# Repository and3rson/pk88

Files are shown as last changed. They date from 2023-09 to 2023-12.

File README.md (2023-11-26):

# PK88

Single-board computer based on KM1810VM88 CPU (Ukrainian clone of Intel 8088) that can run ELKS!

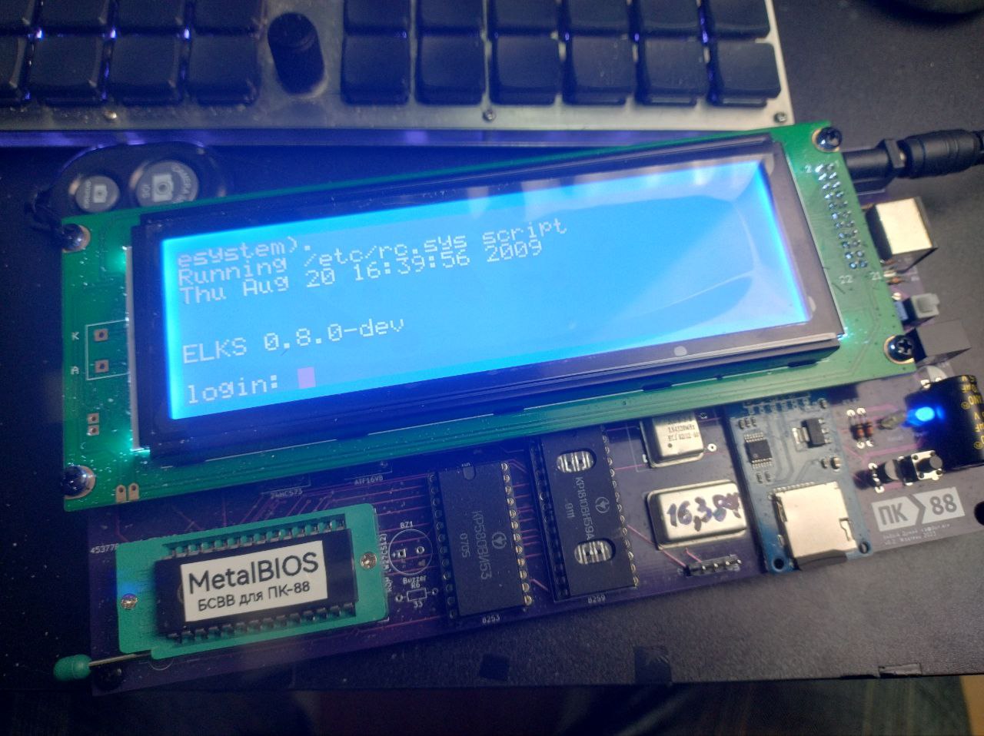
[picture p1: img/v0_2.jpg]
ELKS


PK stands for Персональний Комп'ютер ("Personalnii Kompyuter", i.e. "Personal Computer") in Ukrainian.

This board runs @ 8 MHz (24 MHz oscillator) in minimum mode.

- [KiCad schematics](./kicad)
- [GAL sources](./gal) - Address & I/O port decoders using 2x ATF16V8
- [Various circuit simulations](./circuits) - made with [Digital](https://github.com/hneemann/Digital)
- [MetalBIOS](./metalbios) - IBM PC XT compatible-ish BIOS that I made specifically for PK-88

## Resources

- 8088/x86 instruction set: <https://zsmith.co/intel.php>
- Zen of Assembly language (including 8088 instruction set): <http://www.jagregory.com/abrash-zen-of-asm/>
- Soviet IC series differences: <http://vozom.ho.ua/R4/page21.html>
- IBM PC technical reference: <http://bitsavers.informatik.uni-stuttgart.de/pdf/ibm/pc/at/6183355_PC_AT_Technical_Reference_Mar86.pdf>

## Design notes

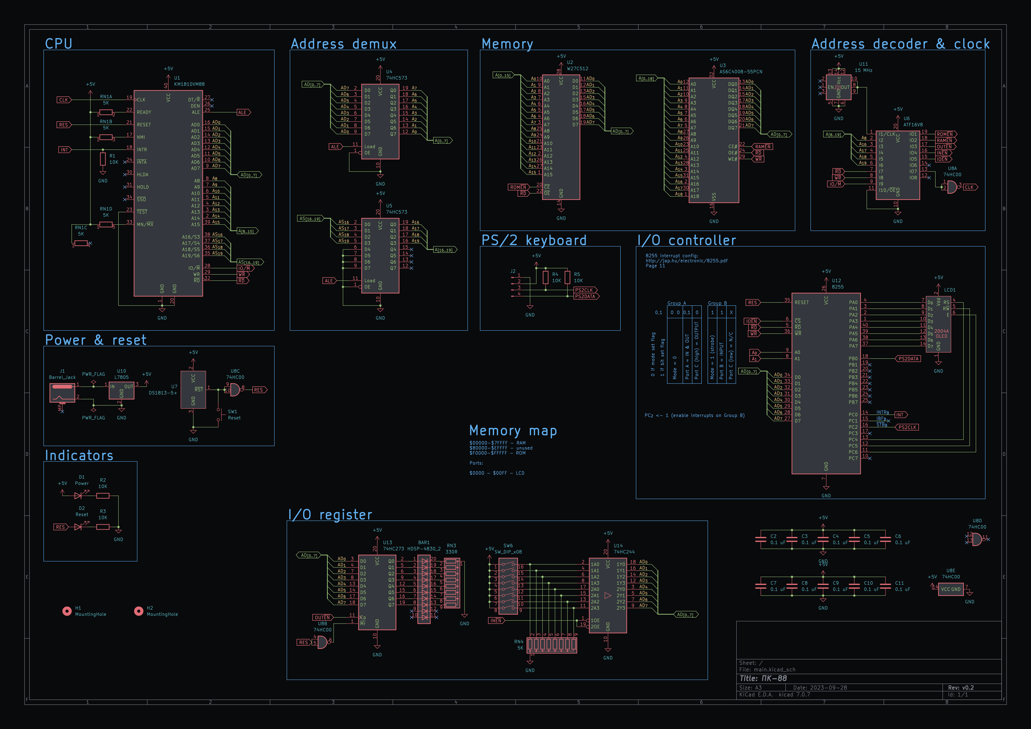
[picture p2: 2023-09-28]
img/v02_schematic.png

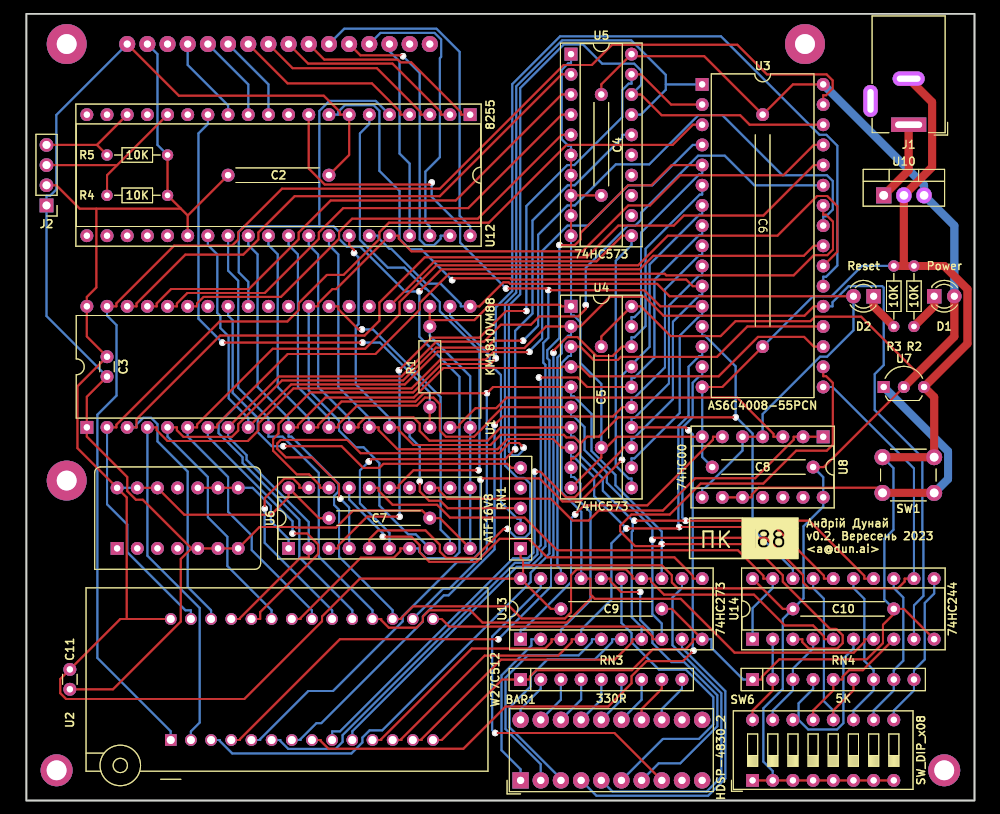
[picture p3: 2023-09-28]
img/v02_pcb_1.png

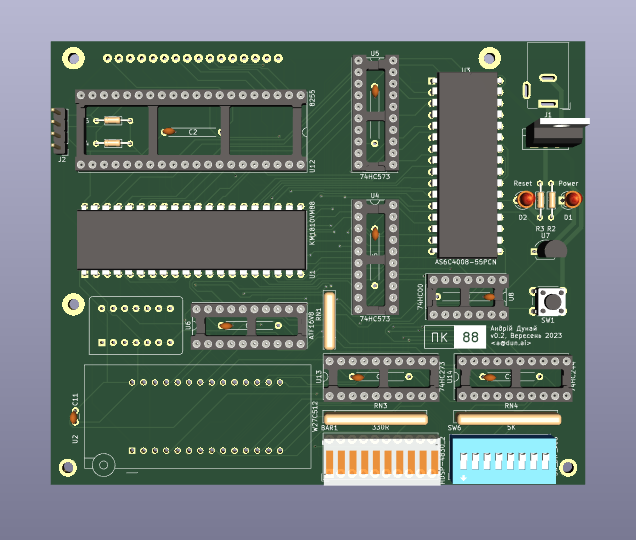
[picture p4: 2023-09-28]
img/v02_3d.png

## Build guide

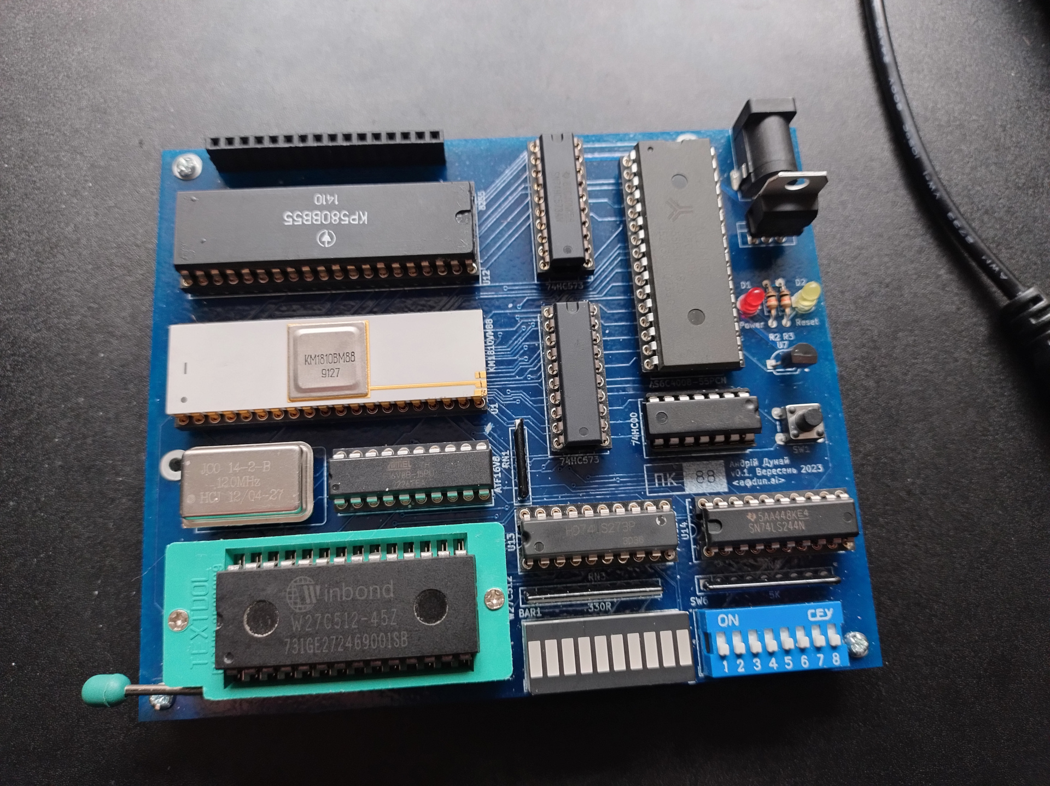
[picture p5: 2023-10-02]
img/v0_1_assembled1.jpg

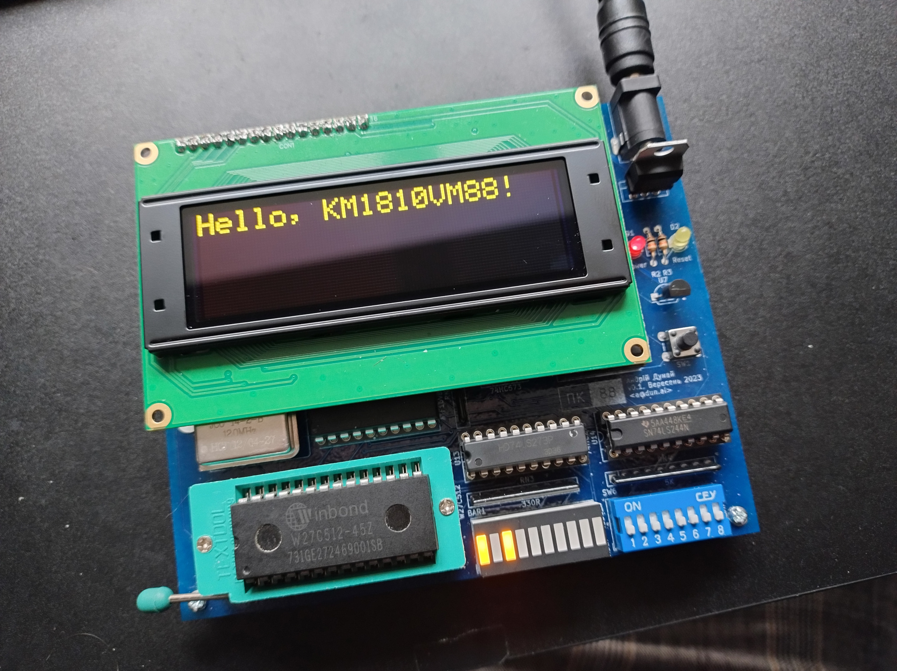
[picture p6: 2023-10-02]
img/v0_1_assembled2.jpg

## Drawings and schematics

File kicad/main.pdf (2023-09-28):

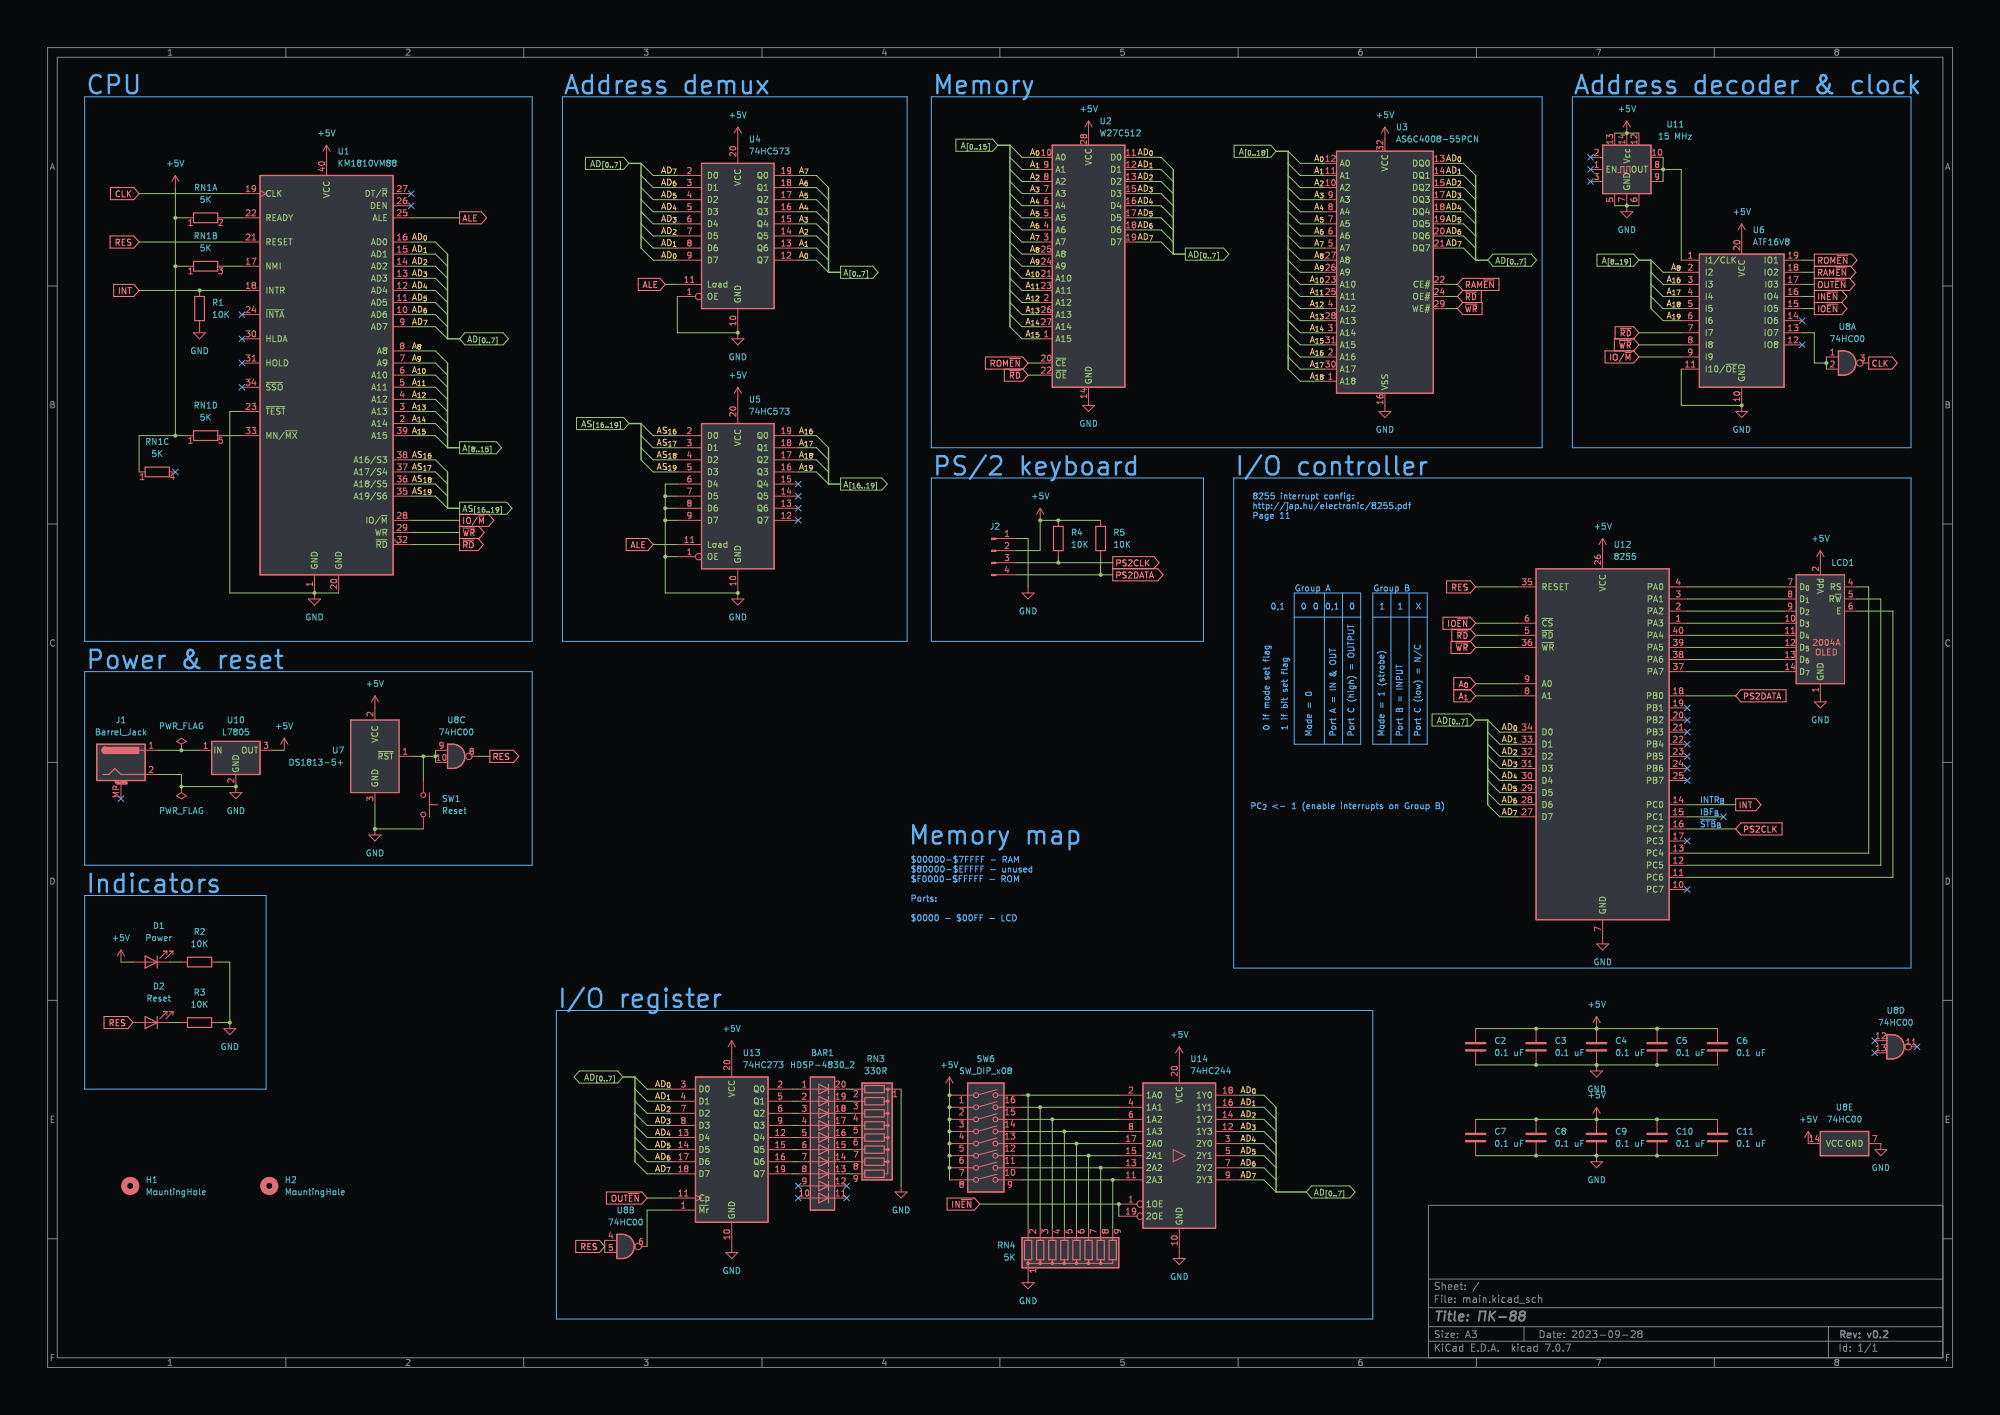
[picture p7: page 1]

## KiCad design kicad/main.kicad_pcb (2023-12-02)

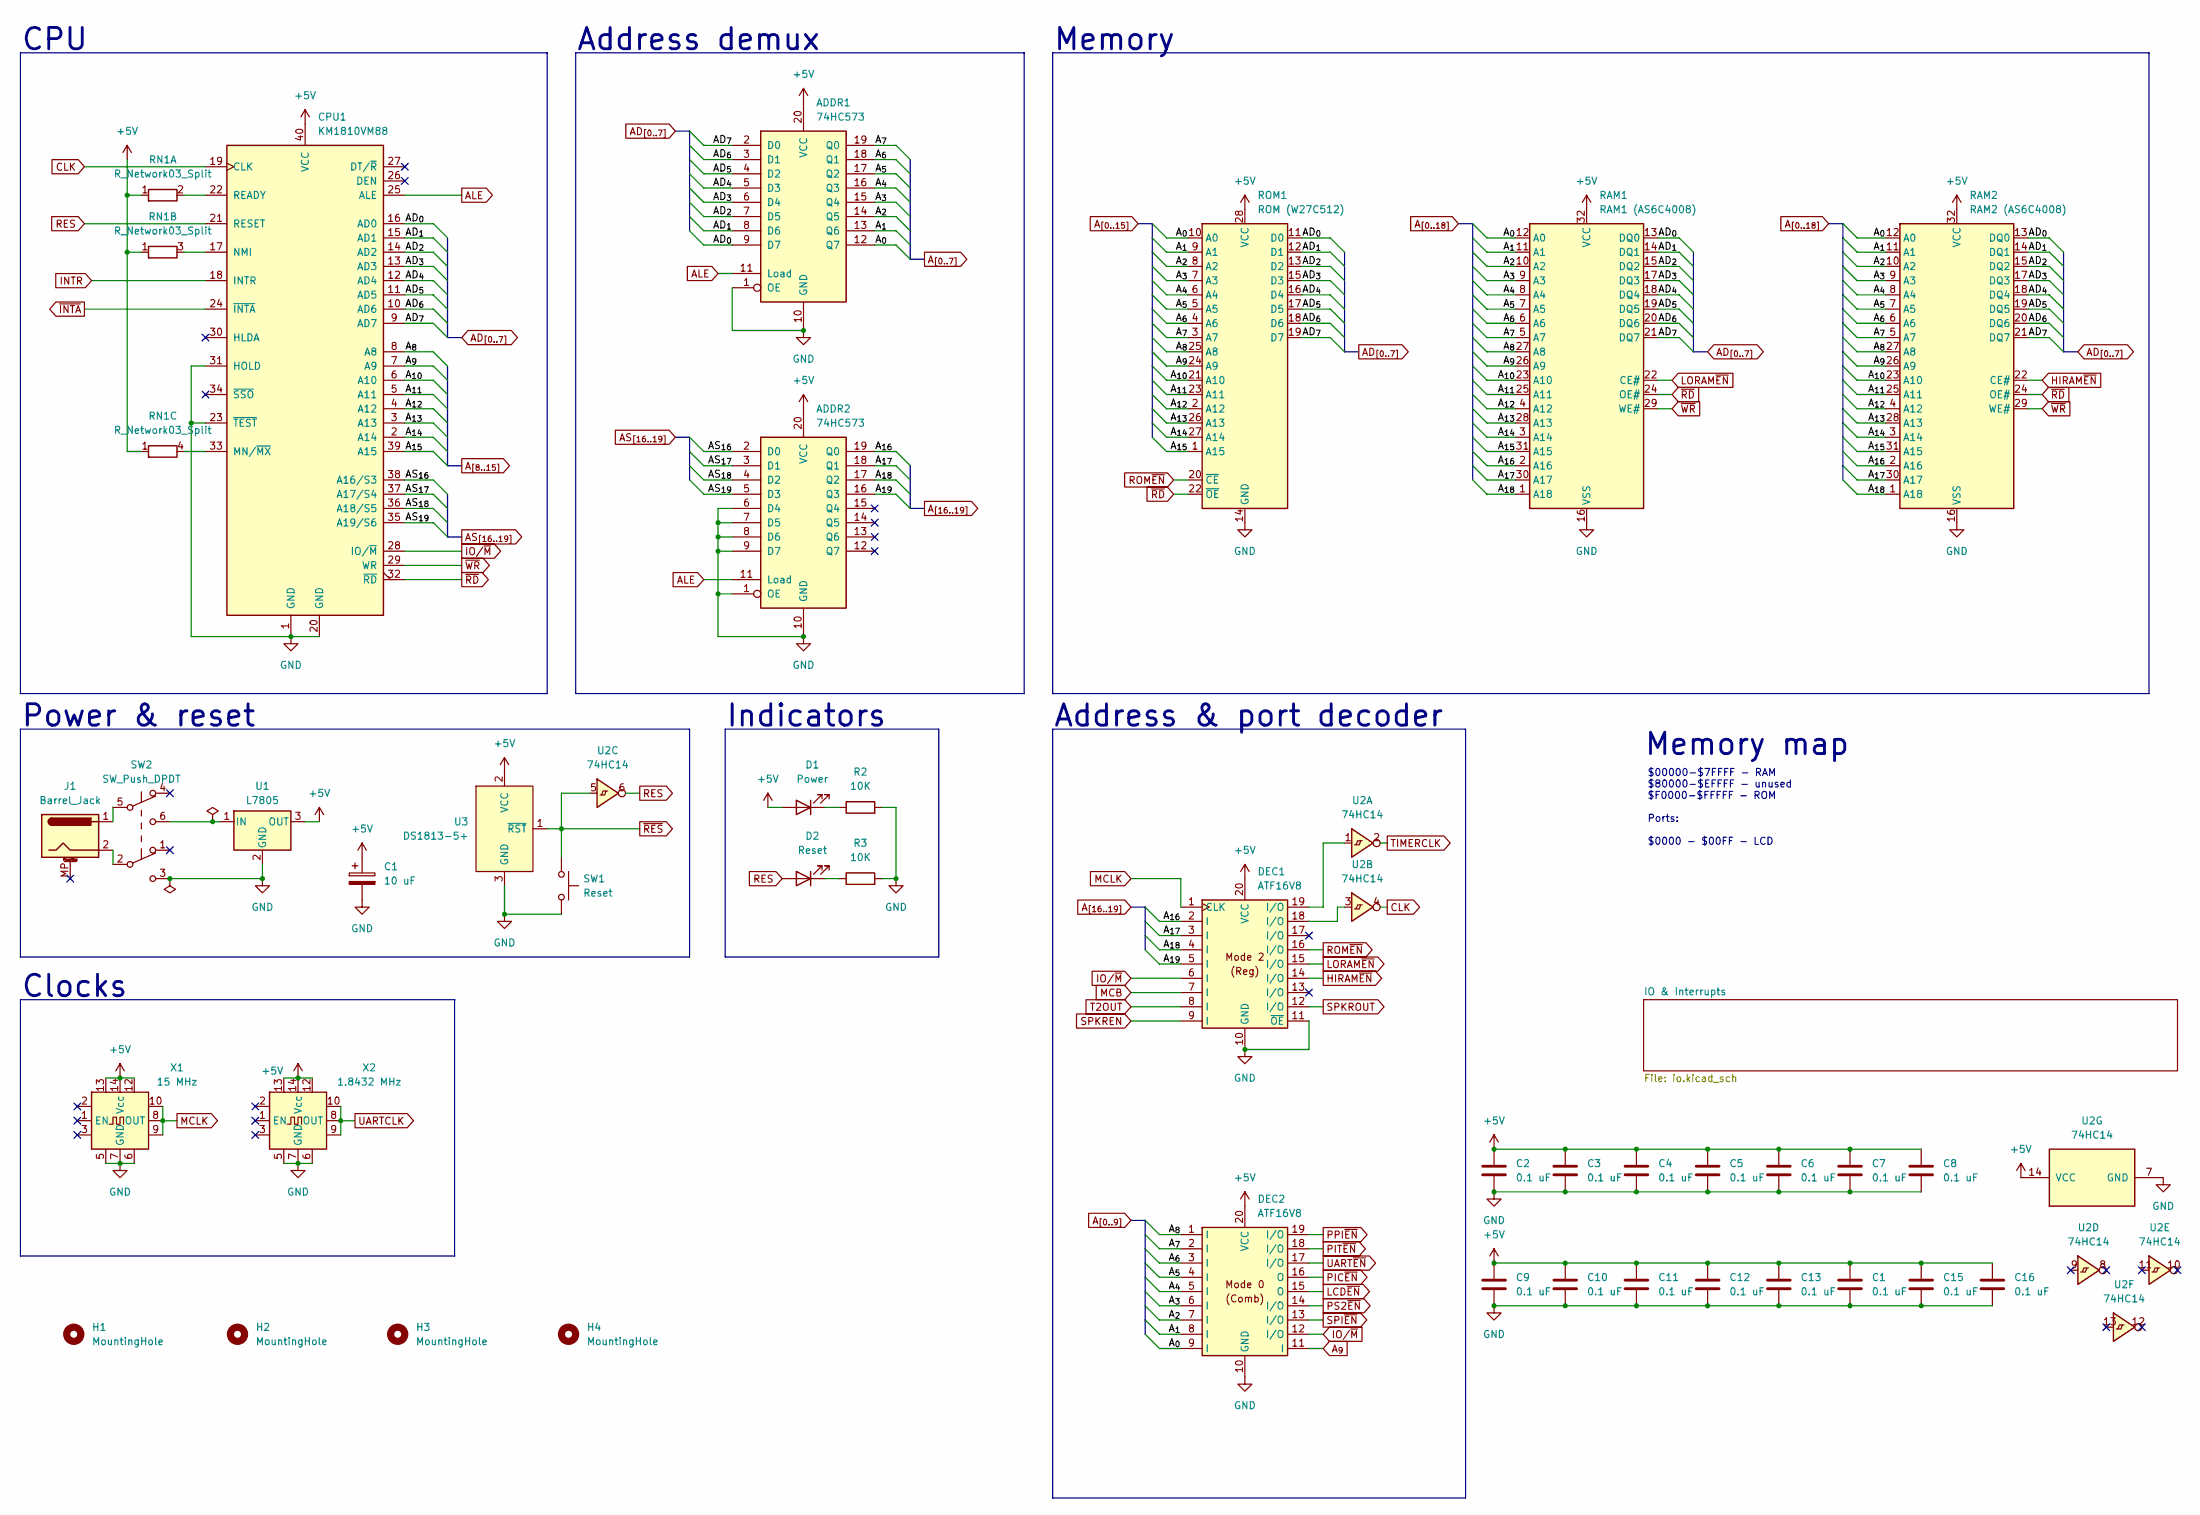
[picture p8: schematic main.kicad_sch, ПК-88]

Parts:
ADDR1, ADDR2: 74HC573; DIP-20_W7.62mm_Socket
C1: 10 uF; CP_Radial_D8.0mm_P3.50mm
C2, C4, C5, C7, C8, C10, C15, C16: 0.1 uF; C_Disc_Long
C3, C11: 0.1 uF; C_Disc_D3.0mm_W1.6mm_P2.50mm
C6, C9, C12, C13: 0.1 uF; C_Disc_VeryLong
CPU1: KM1810VM88; DIP-40_W15.24mm
D1: Power; LED_D3.0mm
D2: Reset; LED_D3.0mm
DEC1, DEC2: ATF16V8; DIP-20_W7.62mm_Socket
H1, H2, H3, H4: MountingHole; Hole_3.5x5
J1: Barrel_Jack; BarrelJack_Wuerth_6941xx301002
R2, R3: 10K; R_Axial_DIN0204_L3.6mm_D1.6mm_P7.62mm_Horizontal
RAM1: RAM1 (AS6C4008); DIP-32_W15.24mm
RAM2: RAM2 (AS6C4008); DIP-32_W15.24mm
RN1: R_Network03_Split; R_Array_SIP4
ROM1: ROM (W27C512); ZIF28
SW1: Reset; SW_PUSH_6mm_H5mm
SW2: SW_Push_DPDT; PB22E06
U1: L7805; TO-220-3_Vertical
U2: 74HC14; DIP-14_W7.62mm_Socket
U3: DS1813-5+; TO-92L_Inline_Wide
X1: 15 MHz; Oscillator_DIP-8-14
X2: 1.8432 MHz; Oscillator_DIP-8-14

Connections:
+5V: ADDR1.20 (VCC), ADDR2.20 (VCC), C1.1, C2.1, C3.1, C4.1, C5.1, C6.1, C7.1, C8.1, C9.1, C10.1, C11.1, C12.1, C13.1, C15.1, C16.1, CPU1.40 (VCC), D1.2 (A), DEC1.20 (VCC), DEC2.20 (VCC), RAM1.32 (VCC), RAM2.32 (VCC), RN1.1 (R1), ROM1.28 (VCC), U1.3 (OUT), U2.14 (VCC), U3.2 (VCC), X1.12, X1.13, X1.14 (Vcc), X2.12, X2.13, X2.14 (Vcc); also elsewhere on the board
AD_{0}: ADDR1.9 (D7), CPU1.16 (AD0), RAM1.13 (DQ0), RAM2.13 (DQ0), ROM1.11 (D0); also elsewhere on the board
AD_{1}: ADDR1.8 (D6), CPU1.15 (AD1), RAM1.14 (DQ1), RAM2.14 (DQ1), ROM1.12 (D1); also elsewhere on the board
AD_{2}: ADDR1.7 (D5), CPU1.14 (AD2), RAM1.15 (DQ2), RAM2.15 (DQ2), ROM1.13 (D2); also elsewhere on the board
AD_{3}: ADDR1.6 (D4), CPU1.13 (AD3), RAM1.17 (DQ3), RAM2.17 (DQ3), ROM1.15 (D3); also elsewhere on the board
AD_{4}: ADDR1.5 (D3), CPU1.12 (AD4), RAM1.18 (DQ4), RAM2.18 (DQ4), ROM1.16 (D4); also elsewhere on the board
AD_{5}: ADDR1.4 (D2), CPU1.11 (AD5), RAM1.19 (DQ5), RAM2.19 (DQ5), ROM1.17 (D5); also elsewhere on the board
AD_{6}: ADDR1.3 (D1), CPU1.10 (AD6), RAM1.20 (DQ6), RAM2.20 (DQ6), ROM1.18 (D6); also elsewhere on the board
AD_{7}: ADDR1.2 (D0), CPU1.9 (AD7), RAM1.21 (DQ7), RAM2.21 (DQ7), ROM1.19 (D7); also elsewhere on the board
ALE: ADDR1.11 (Load), ADDR2.11 (Load), CPU1.25 (ALE)
AS_{16}: ADDR2.2 (D0), CPU1.38 (A16/S3)
AS_{17}: ADDR2.3 (D1), CPU1.37 (A17/S4)
AS_{18}: ADDR2.4 (D2), CPU1.36 (A18/S5)
AS_{19}: ADDR2.5 (D3), CPU1.35 (A19/S6)
A_{0}: ADDR1.12 (Q7), DEC2.9 (I), RAM1.12 (A0), RAM2.12 (A0), ROM1.10 (A0); also elsewhere on the board
A_{1}: ADDR1.13 (Q6), DEC2.8 (I), RAM1.11 (A1), RAM2.11 (A1), ROM1.9 (A1); also elsewhere on the board
A_{2}: ADDR1.14 (Q5), DEC2.7 (I), RAM1.10 (A2), RAM2.10 (A2), ROM1.8 (A2); also elsewhere on the board
A_{3}: ADDR1.15 (Q4), DEC2.6 (I), RAM1.9 (A3), RAM2.9 (A3), ROM1.7 (A3)
A_{4}: ADDR1.16 (Q3), DEC2.5 (I), RAM1.8 (A4), RAM2.8 (A4), ROM1.6 (A4)
A_{5}: ADDR1.17 (Q2), DEC2.4 (I), RAM1.7 (A5), RAM2.7 (A5), ROM1.5 (A5)
A_{6}: ADDR1.18 (Q1), DEC2.3 (I), RAM1.6 (A6), RAM2.6 (A6), ROM1.4 (A6)
A_{7}: ADDR1.19 (Q0), DEC2.2 (I), RAM1.5 (A7), RAM2.5 (A7), ROM1.3 (A7)
A_{8}: CPU1.8 (A8), DEC2.1 (I), RAM1.27 (A8), RAM2.27 (A8), ROM1.25 (A8)
A_{9}: CPU1.7 (A9), DEC2.11 (I), RAM1.26 (A9), RAM2.26 (A9), ROM1.24 (A9)
A_{10}: CPU1.6 (A10), RAM1.23 (A10), RAM2.23 (A10), ROM1.21 (A10)
A_{11}: CPU1.5 (A11), RAM1.25 (A11), RAM2.25 (A11), ROM1.23 (A11)
A_{12}: CPU1.4 (A12), RAM1.4 (A12), RAM2.4 (A12), ROM1.2 (A12)
A_{13}: CPU1.3 (A13), RAM1.28 (A13), RAM2.28 (A13), ROM1.26 (A13)
A_{14}: CPU1.2 (A14), RAM1.3 (A14), RAM2.3 (A14), ROM1.27 (A14)
A_{15}: CPU1.39 (A15), RAM1.31 (A15), RAM2.31 (A15), ROM1.1 (A15)
A_{16}: ADDR2.19 (Q0), DEC1.2 (I), RAM1.2 (A16), RAM2.2 (A16)
A_{17}: ADDR2.18 (Q1), DEC1.3 (I), RAM1.30 (A17), RAM2.30 (A17)
A_{18}: ADDR2.17 (Q2), DEC1.4 (I), RAM1.1 (A18), RAM2.1 (A18)
A_{19}: ADDR2.16 (Q3), DEC1.5 (I)
CLK: CPU1.19 (CLK), U2.4; also elsewhere on the board
HIRAM~EN: DEC1.14 (I/O), RAM2.22 (CE#)
INTR: CPU1.18 (INTR); also elsewhere on the board
IO/~M: CPU1.28 (IO/~M), DEC1.6 (I), DEC2.12 (I/O)
LCD~EN: DEC2.15 (O); also elsewhere on the board
LORAM~EN: DEC1.15 (I/O), RAM1.22 (CE#)
MCLK: DEC1.1 (CLK), X1.8 (OUT), X1.9, X1.10
unnamed: CPU1.33 (MN/~MX), RN1.4 (R3.2)
unnamed: CPU1.17 (NMI), RN1.3 (R2.2)
unnamed: CPU1.22 (READY), RN1.2 (R1.2)
unnamed: D2.1 (K), R3.1
unnamed: DEC1.18 (I/O), U2.3
unnamed: DEC1.19 (I/O), U2.1
unnamed: J1.1, SW2.5 (B)
unnamed: J1.2, SW2.2 (B)
unnamed: SW2.6 (C), U1.1 (IN)
PIC~EN: DEC2.16 (O); also elsewhere on the board
PIT~EN: DEC2.18 (I/O); also elsewhere on the board
PPI~EN: DEC2.19 (I/O); also elsewhere on the board
PS2~EN: DEC2.14 (I/O); also elsewhere on the board
RES: CPU1.21 (RESET), D2.2 (A), U2.6; also elsewhere on the board
ROM~EN: DEC1.16 (I/O), ROM1.20 (~CE)
SPI~EN: DEC2.13 (I/O); also elsewhere on the board
SPKREN: DEC1.9 (I); also elsewhere on the board
SPKROUT: DEC1.12 (I/O); also elsewhere on the board
T2OUT: DEC1.8 (I); also elsewhere on the board
TIMERCLK: U2.2; also elsewhere on the board
UARTCLK: X2.8 (OUT), X2.9, X2.10; also elsewhere on the board
UART~EN: DEC2.17 (I/O); also elsewhere on the board
~INTA: CPU1.24 (~INTA); also elsewhere on the board
~RD: CPU1.32 (~RD), RAM1.24 (OE#), RAM2.24 (OE#), ROM1.22 (~OE); also elsewhere on the board
~RES: SW1.1, U2.5, U3.1 (~RST); also elsewhere on the board
~WR: CPU1.29 (WR), RAM1.29 (WE#), RAM2.29 (WE#); also elsewhere on the board

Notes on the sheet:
Address & port decoder
Clocks
Power & reset
Address demux
Indicators
Memory
$00000-$7FFFF - RAM $80000-$EFFFF - unused $F0000-$FFFFF - ROM Ports: $0000 - $00FF - LCD
Memory map
CPU

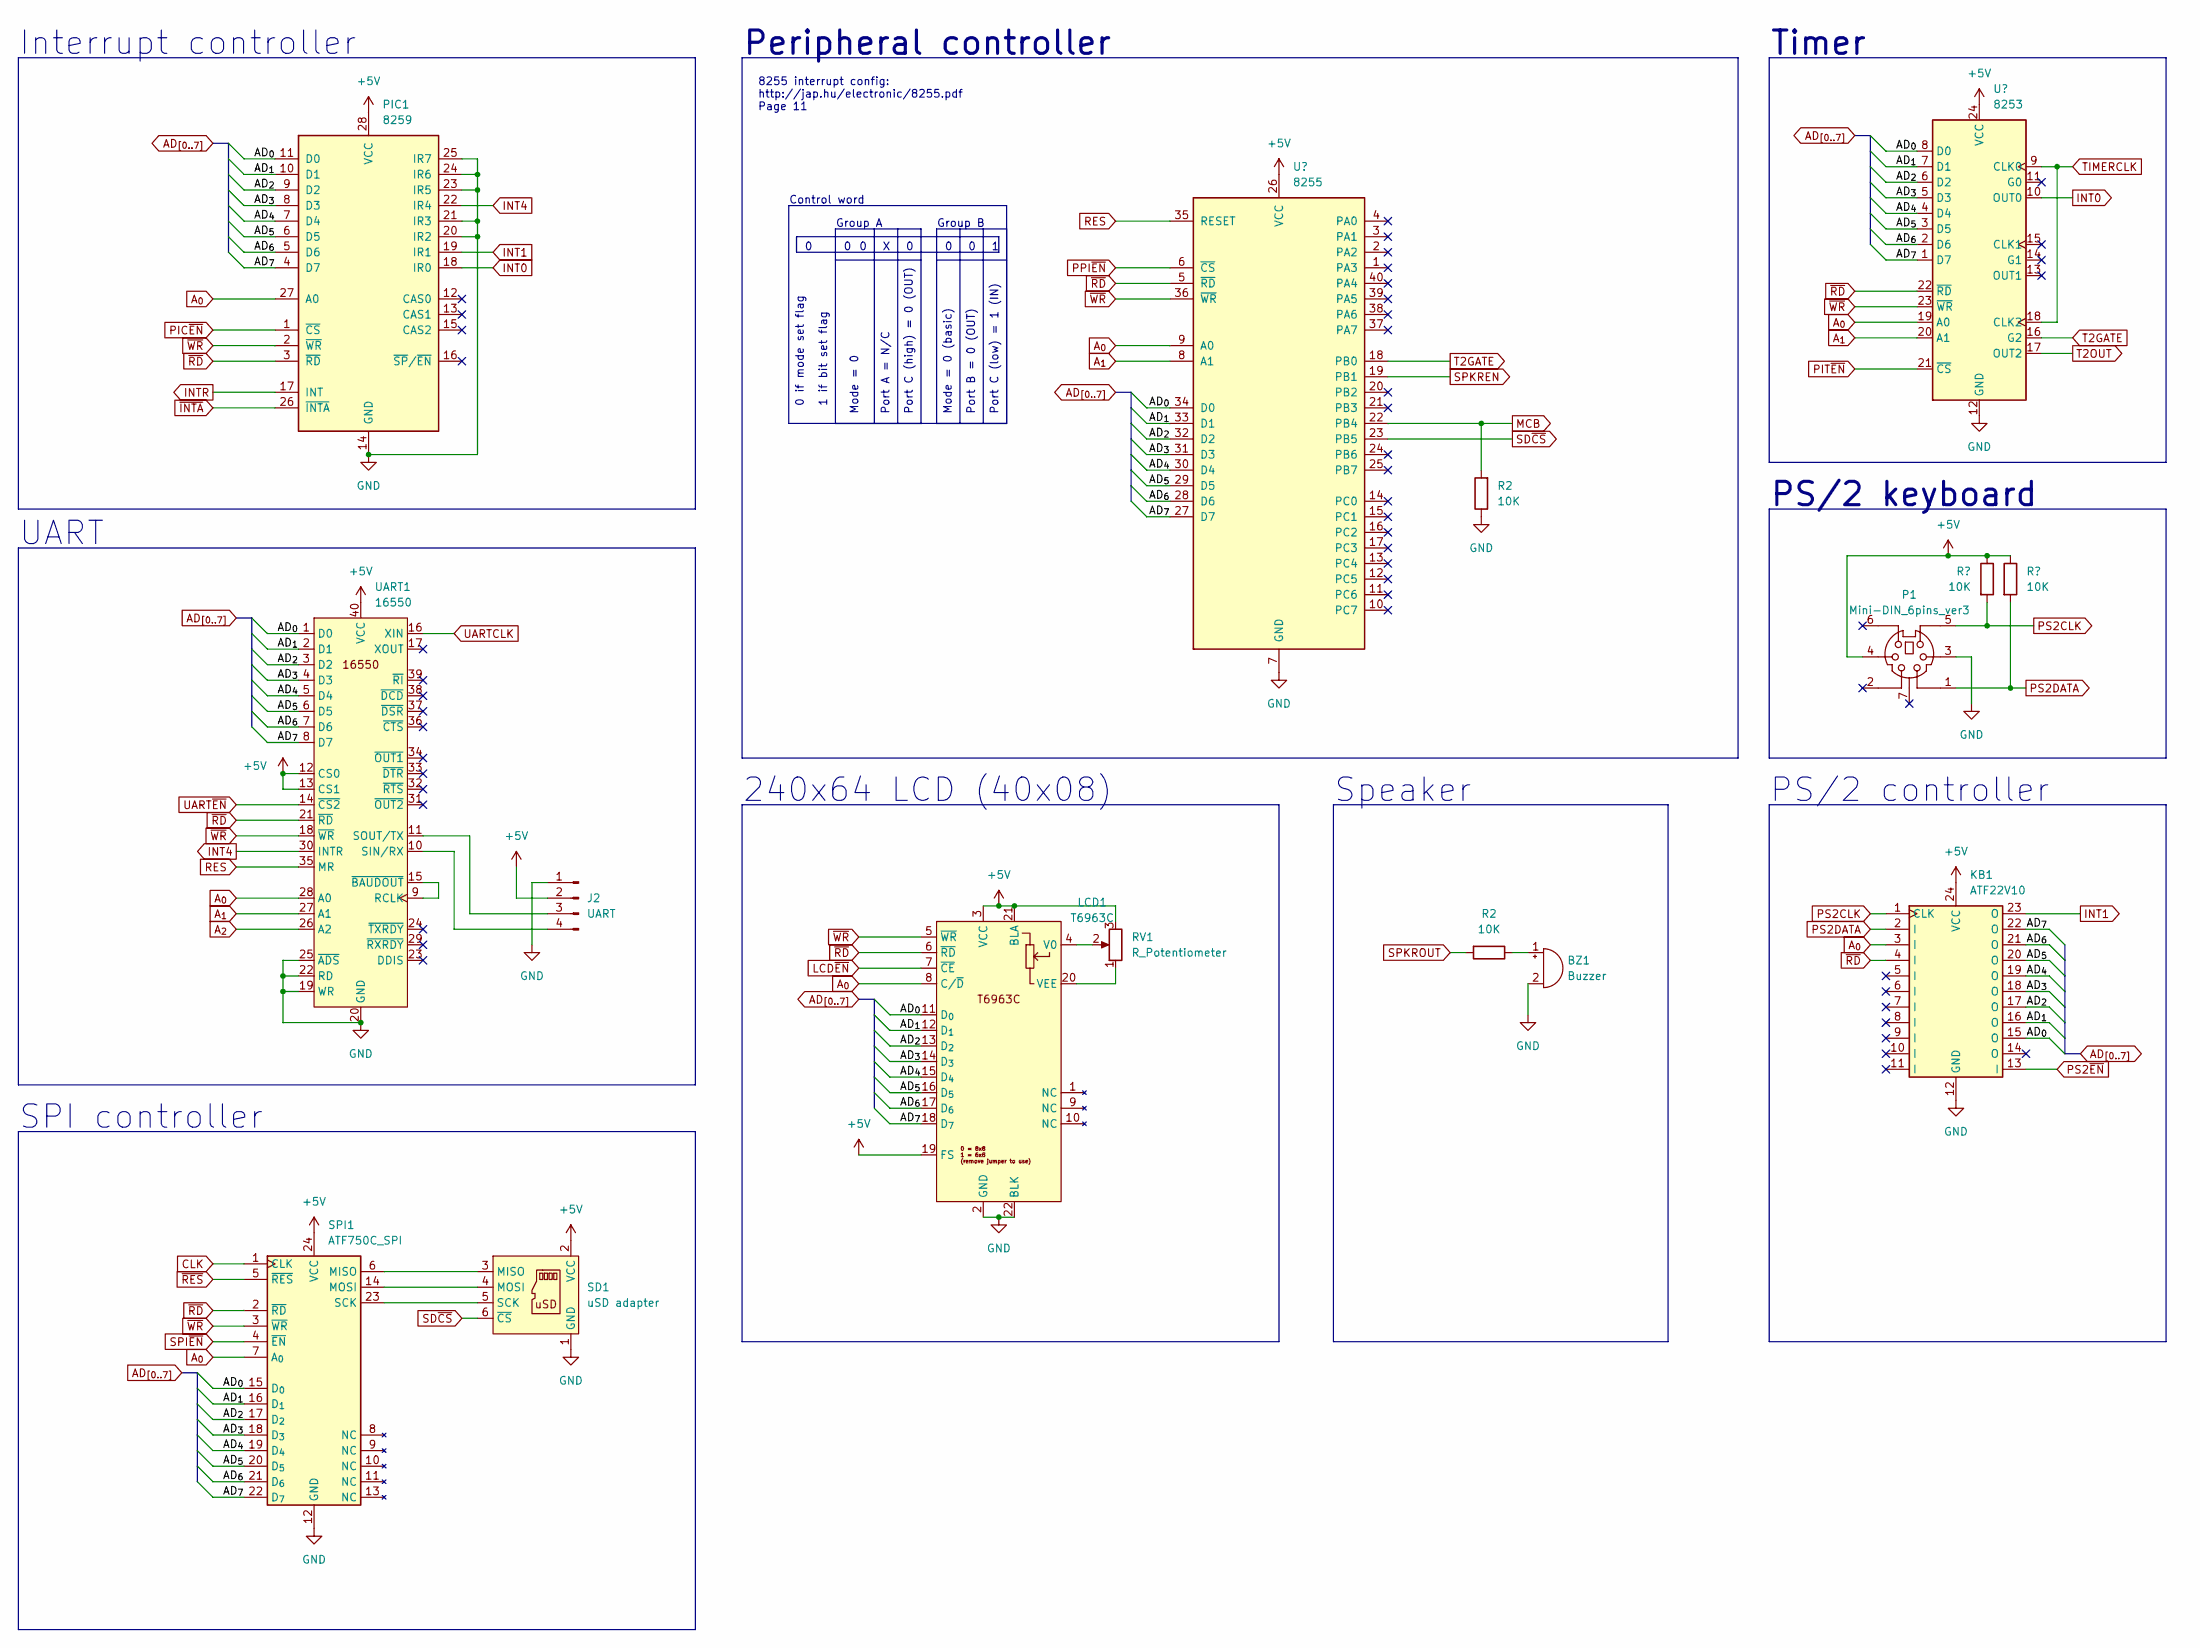
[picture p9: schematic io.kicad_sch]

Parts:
BZ1: Buzzer; Buzzer_TDK_PS1240P02BT_D12.2mm_H6.5mm
J2: UART; PinHeader_1x04_P2.54mm_Vertical
KB1: ATF22V10; DIP-24_W7.62mm_Socket
LCD1: T6963C; LCD240128_TFT_var2
P1: Mini-DIN_6pins_ver3; Connector_Mini-DIN_Female_6Pin_2rows
PIC1: 8259; DIP-28_W15.24mm_Socket
PIT1: 8253; DIP-24_W15.24mm
PPI1: 8255; DIP-40_W15.24mm
R2, R4, R5: 10K; R_Axial_DIN0204_L3.6mm_D1.6mm_P7.62mm_Horizontal
RV1: R_Potentiometer; Potentiometer_Bourns_3296Y_Vertical
SD1: uSD adapter; MicroSD-Adapter
SPI1: ATF750C_SPI; DIP-24_W7.62mm_Socket
UART1: 16550; DIP-40_W15.24mm_Socket

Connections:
+5V: J2.2, KB1.24 (VCC), LCD1.3 (VCC), LCD1.19 (FS), LCD1.21 (BLA), P1.4, PIC1.28 (VCC), PIT1.24 (VCC), PPI1.26 (VCC), R4.1, R5.1, RV1.3, SD1.2 (VCC), SPI1.24 (VCC), UART1.12 (CS0), UART1.13 (CS1), UART1.40 (VCC); also elsewhere on the board
AD_{0}: KB1.15 (O), LCD1.11 (D_{0}), PIC1.11 (D0), PIT1.8 (D0), PPI1.34 (D0), SPI1.15 (D_{0}), UART1.1 (D0); also elsewhere on the board
AD_{1}: KB1.16 (O), LCD1.12 (D_{1}), PIC1.10 (D1), PIT1.7 (D1), PPI1.33 (D1), SPI1.16 (D_{1}), UART1.2 (D1); also elsewhere on the board
AD_{2}: KB1.17 (O), LCD1.13 (D_{2}), PIC1.9 (D2), PIT1.6 (D2), PPI1.32 (D2), SPI1.17 (D_{2}), UART1.3 (D2); also elsewhere on the board
AD_{3}: KB1.18 (O), LCD1.14 (D_{3}), PIC1.8 (D3), PIT1.5 (D3), PPI1.31 (D3), SPI1.18 (D_{3}), UART1.4 (D3); also elsewhere on the board
AD_{4}: KB1.19 (O), LCD1.15 (D_{4}), PIC1.7 (D4), PIT1.4 (D4), PPI1.30 (D4), SPI1.19 (D_{4}), UART1.5 (D4); also elsewhere on the board
AD_{5}: KB1.20 (O), LCD1.16 (D_{5}), PIC1.6 (D5), PIT1.3 (D5), PPI1.29 (D5), SPI1.20 (D_{5}), UART1.6 (D5); also elsewhere on the board
AD_{6}: KB1.21 (O), LCD1.17 (D_{6}), PIC1.5 (D6), PIT1.2 (D6), PPI1.28 (D6), SPI1.21 (D_{6}), UART1.7 (D6); also elsewhere on the board
AD_{7}: KB1.22 (O), LCD1.18 (D_{7}), PIC1.4 (D7), PIT1.1 (D7), PPI1.27 (D7), SPI1.22 (D_{7}), UART1.8 (D7); also elsewhere on the board
A_{0}: KB1.3 (I), LCD1.8 (C/~D), PIC1.27 (A0), PIT1.19 (A0), PPI1.9 (A0), SPI1.7 (A_{0}), UART1.28 (A0); also elsewhere on the board
A_{1}: PIT1.20 (A1), PPI1.8 (A1), UART1.27 (A1); also elsewhere on the board
A_{2}: UART1.26 (A2); also elsewhere on the board
CLK: SPI1.1 (CLK); also elsewhere on the board
INT0: PIC1.18 (IR0), PIT1.10 (OUT0)
INT1: KB1.23 (O), PIC1.19 (IR1)
INT4: PIC1.22 (IR4), UART1.30 (INTR)
INTR: PIC1.17 (INT); also elsewhere on the board
LCD~EN: LCD1.7 (~CE); also elsewhere on the board
unnamed: J2.3, UART1.11 (SOUT/TX)
unnamed: J2.4, UART1.10 (SIN/RX)
unnamed: LCD1.4 (V0), RV1.2
unnamed: LCD1.20 (VEE), RV1.1
unnamed: SD1.3 (MISO), SPI1.6 (MISO)
unnamed: SD1.4 (MOSI), SPI1.14 (MOSI)
unnamed: SD1.5 (SCK), SPI1.23 (SCK)
unnamed: UART1.9 (RCLK), UART1.15 (~BAUDOUT)
PIC~EN: PIC1.1 (~CS); also elsewhere on the board
PIT~EN: PIT1.21 (~CS); also elsewhere on the board
PPI~EN: PPI1.6 (~CS); also elsewhere on the board
PS2CLK: KB1.1 (CLK), P1.5, R4.2
PS2DATA: KB1.2 (I), P1.1, R5.2
PS2~EN: KB1.13 (I); also elsewhere on the board
RES: PPI1.35 (RESET), UART1.35 (MR); also elsewhere on the board
SD~CS: PPI1.23 (PB5), SD1.6 (~CS)
SPI~EN: SPI1.4 (~EN); also elsewhere on the board
SPKREN: PPI1.19 (PB1); also elsewhere on the board
T2GATE: PIT1.16 (G2), PPI1.18 (PB0)
T2OUT: PIT1.17 (OUT2); also elsewhere on the board
TIMERCLK: PIT1.9 (CLK0), PIT1.18 (CLK2); also elsewhere on the board
UARTCLK: UART1.16 (XIN); also elsewhere on the board
UART~EN: UART1.14 (~CS2); also elsewhere on the board
~INTA: PIC1.26 (~INTA); also elsewhere on the board
~RD: KB1.4 (I), LCD1.6 (~RD), PIC1.3 (~RD), PIT1.22 (~RD), PPI1.5 (~RD), SPI1.2 (~RD), UART1.21 (~RD); also elsewhere on the board
~RES: SPI1.5 (~RES); also elsewhere on the board
~WR: LCD1.5 (~WR), PIC1.2 (~WR), PIT1.23 (~WR), PPI1.36 (~WR), SPI1.3 (~WR), UART1.18 (~WR); also elsewhere on the board

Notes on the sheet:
0 if mode set flag
Speaker
SPI controller
Timer
Mode = 0
PS/2 controller
240x64 LCD (40x08)
Mode = 0 (basic)
Interrupt controller
Peripheral controller
Group A
Control word
Group B
1 if bit set flag
Port B = 0 (OUT)
Port C (high) = 0 (OUT)
Port A = N/C
UART
8255 interrupt config: http://jap.hu/electronic/8255.pdf Page 11
PS/2 keyboard
Port C (low) = 1 (IN)

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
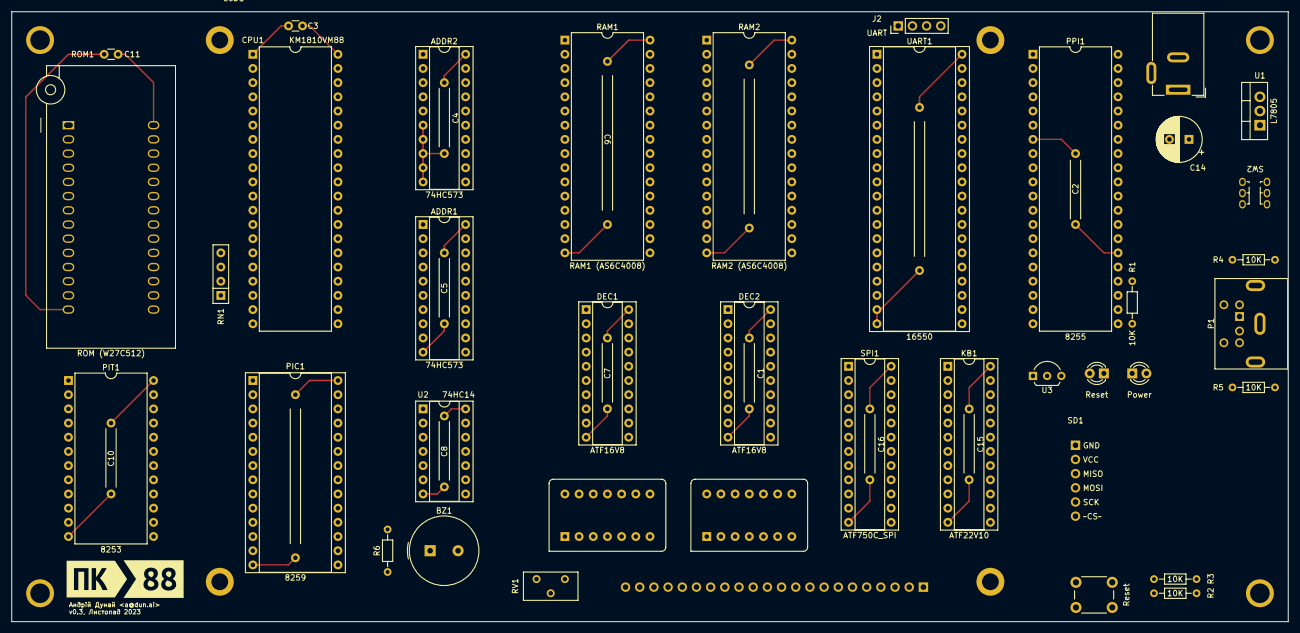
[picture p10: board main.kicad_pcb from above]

Board: 2 copper layers, 228.6 x 109.2 mm, 59 parts (0 on the bottom side), 86 nets.

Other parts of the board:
C14: 10 uF; CP_Radial_D8.0mm_P3.50mm
R1, R6: 10K; R_Axial_DIN0204_L3.6mm_D1.6mm_P7.62mm_Horizontal
kibuzzard-65254FD7: G***; kibuzzard-65254FD7
kibuzzard-65254FDB: G***; kibuzzard-65254FDB

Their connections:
+5V: C14.1; also elsewhere on the board
SPKROUT: R6.2; also elsewhere on the board

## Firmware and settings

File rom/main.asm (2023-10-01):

        cpu 8086
        bits 16

START   equ $
ROM_SEG equ 0xF000
STK_SEG equ 0x7800
STK_LEN equ 0x8000  ; 32 KB stack

; DIP switches & LEDs are on port 0x0
IO_LEDS equ 0x0
IO_DIPS equ 0x0
; 8255 is on ports 0x100..0x103
IO_A    equ 0x100
IO_B    equ 0x101
IO_C    equ 0x102
IO_CTRL equ 0x103

        org ROM_SEG*16

HELLO_S db "Hello, KM1810VM88!", 0

init:
        ; Initialize segments
        mov ax, STK_SEG
        mov ss, ax
        mov ax, STK_LEN
        mov sp, ax

        ; Initialize I/O
        mov dx, IO_CTRL
        mov al, 0b10000000
        ; 1 0 0 0 0 0 0 0
        ; ^ ^ ^ ^ ^ ^ ^ ^
        ; | | | | | | | |
        ; | | | | | | | +-- 0: Port C (lower) is output
        ; | +++ | | | +--- 0: Port B is output
        ; |  |  | | +---- 0: Mode 0
        ; |  |  | +----- 0: Port C (upper) is output
        ; |  |  +------ 0: Port A is output
        ; |  +------- 00: Mode 0
        ; +---------- 1: Mode set flag
        out dx, al

        call lcd_init
        mov si, HELLO_S
        call lcd_print
        hlt

;         ; Delay 65536 iterations (~557 (524?) ms)
;         ; (1 iteration takes ~8 us)
; delay:
;         inc cx
;         cmp cx, 0
;         jne delay

; Initialize LCD
lcd_init:
        push ax
        push cx

        xor cx, cx
.longinit:
        mov ah, 0
        mov al, 0b00111000  ; 8 bit, 2 lines, 5x8
        call lcd_write
        call lcd_busy

        inc cx
        cmp cx, 0x3
        jne .longinit

        mov al, 0b00001111  ; Display on, cursor on, blink on
        call lcd_write
        call lcd_busy

        mov al, 0b00000001  ; Clear display
        call lcd_write
        call lcd_busy

        mov al, 0b00000110  ; Increment cursor, no shift
        call lcd_write
        call lcd_busy

        mov al, 0b00000010  ; Return home
        call lcd_write
        call lcd_busy

        mov al, 0b10000000  ; Set DDRAM address
        call lcd_write
        call lcd_busy

        pop cx
        pop ax

        ret

; Print string to LCD
; Args:
;   DS:SI - string
lcd_print:
        push ax
        push si

        mov ah, 1
        mov si, HELLO_S
.next:
        mov al, [ds:si]
        cmp al, 0
        je .done
        call lcd_write
        call lcd_busy
        inc si
        jmp .next

.done:
        pop si
        pop ax

        ret


; Args:
;   AL - data
;   AH - register
lcd_write:
        push bx
        push dx
        mov bx, ax

        mov dx, IO_CTRL
        ; in al, dx
        ; and al, 0b11101111  ; Set port A to output
        ; or al, 0b10000000  ; Mode set flag
        mov al, 0b10000000
        out dx, al

        mov al, bl  ; Restore AL = data

        xchg ah, al  ; AL = register
        and al, 0b11111101  ; R/W = 0
        mov dx, IO_B
        out dx, al

        xchg ah, al  ; AL = data
        mov dx, IO_A
        out dx, al

        nop
        nop
        nop
        nop
        nop
        nop
        nop
        nop

        xchg ah, al  ; AL = register
        or al, 0b00000100  ; E = 1
        mov dx, IO_B
        out dx, al
        ; mov dx, IO_LEDS
        ; out dx, al

        nop
        nop
        nop
        nop
        nop
        nop
        nop
        nop

        and al, 0b11111011  ; E = 0
        mov dx, IO_B
        out dx, al

        mov ax, bx  ; Restore args
        pop dx
        pop bx

        ret

; Args:
;   AH - register
;
; Return:
;   AL - data
lcd_read:
        push bx
        push dx
        mov bx, ax

        mov dx, IO_CTRL
        ; in al, dx
        ; or al, 0b10010000  ; Set port A to input
        mov al, 0b10010000
        out dx, al

        mov al, bl  ; Restore AL = data

        xchg ah, al  ; AL = register
        or al, 0b00000010  ; R/W = 1
        mov dx, IO_B
        out dx, al

        or al, 0b00000100  ; E = 1
        mov dx, IO_B
        out dx, al

        nop
        nop
        nop
        nop
        nop
        nop
        nop
        nop

        xchg ah, al  ; AL = data
        mov dx, IO_A
        in al, dx  ; Read data

        xchg ah, al  ; AL = register, AH = data
        and al, 0b11111011  ; E = 0
        mov dx, IO_B
        out dx, al

        xchg ah, al  ; AL = data, AH = register

        mov ah, bh  ; Restore AH = register
        pop dx
        pop bx

        ret


; Block while LCD is busy
lcd_busy:
        push ax
        mov ah, 0
.wait:
        call lcd_read
        and al, 0b10000000
        jnz .wait
        pop ax
        ret

times 0x10000-($-START)-16 db 0xAD

reset:
        jmp ROM_SEG:init
        hlt

times 0x10000-($-START)-2 db 0xAD

        db "AD"

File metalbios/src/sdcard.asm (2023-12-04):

; =====================================================
;
; SD card functions (via 16550)
; https://media.digikey.com/pdf/Data%20Sheets/Texas%20Instruments%20PDFs/PC16550D.pdf
;
; This file is part of MetalBIOS for PK-88.
;
; =====================================================


        cpu     8086
        bits    16

        %include "ports.inc"

SDC_HEADER      equ     01000000b

        section .text

; ==================================================
; SD card functions
; ==================================================

; --------------------------------------------------
; Initialize SD card
; --------------------------------------------------
; Return:
;   AX - error code, 0 if success
        global  sdc_init
sdc_init:
        ; Init lines
        push    bx      ; Clobbered by read
        push    cx

        mov     al, 00000000b
        out     UA_MCR, al
        mov     al, 11111111b
        out     UA_MCR, al
        mov     al, 00000000b
        out     UA_MCR, al
        mov     al, 11111111b
        out     UA_MCR, al

        mov     al, 00001101b   ; MOSI=0, /CS=1, SCK=0
        out     UA_MCR, al

        ; Reset SD card
        mov     al, 00000001b   ; MOSI=1, /CS=1, SCK=0
        out     UA_MCR, al
        mov     cx, 80  ; Sent 80 clock pulses
.loop:
        and     al, 11111110b   ; SCK = 1
        out     UA_MCR, al
        or      al, 00000001b   ; SCK = 0
        out     UA_MCR, al
        loop    .loop

        call    enable

        ; CMD0 - init
        call    cmd0_go_idle_state
        call    wait_byte
        cmp     al, 1
        jne     .go_idle_state_fail

        ; CMD8 - send voltage check
        call    cmd8_send_if_cond
        call    wait_byte       ; Read header
        mov     cx, 5           ; Skip 5 bytes
        call    skip
        cmp     al, 1
        jne     .if_cond_fail

        ; CMD58 - read OCR
        call    cmd58_read_ocr
        call    wait_byte       ; Read header
        mov     cx, 5           ; Skip 5 bytes
        call    skip
        cmp     al, 1
        jne     .read_ocr_fail

        ; CMD55 - send app cmd
        call    cmd55_app_cmd
        call    wait_byte       ; Read header
        call    skip1           ; Skip tail
        cmp     al, 1
        jne     .app_fail

        ; CMD41 - send app op cond
        call    cmd41_send_op_cond
        call    wait_byte       ; Read header
        call    skip1           ; Skip tail
        cmp     al, 1
        jne     .op_cond_fail

        ; CMD55 - send app cmd
        mov     cx, 0x100
.app_init:
        push    cx
        call    cmd55_app_cmd
        call    wait_byte       ; Read header
        call    skip1           ; Skip tail

        ; CMD41 - send app op cond
        call    cmd41_send_op_cond
        call    wait_byte       ; Read header
        call    skip1           ; Skip tail
        pop     cx
        cmp     al, 0
        je      .app_init_ok
        loop    .app_init

        jmp     .app_init_fail
.app_init_ok:

        ; CMD55 - send app cmd
        call    cmd58_read_ocr
        call    wait_byte       ; Read header
        mov     cx, 5           ; Skip tail
        call    skip
        ; Bit 30 of OCR should now contain 1 (the card is a high-capacity card known as SDHC/SDXC)

        ; CMD16 - set block length
        mov     ax, 512
        call    cmd16_set_blocklen
        call    wait_byte       ; Read header
        call    skip1           ; Skip tail
        cmp     al, 0
        jne     .set_blocklen_fail

        xor     ax, ax
        jmp     .end

.go_idle_state_fail:
        mov     ax, 1
        jmp     .end
.if_cond_fail:
        mov     ax, 2
        jmp     .end
.read_ocr_fail:
        mov     ax, 3
        jmp     .end
.app_fail:
        mov     ax, 4
        jmp     .end
.op_cond_fail:
        mov     ax, 5
        jmp     .end
.app_init_fail:
        mov     ax, 6
        jmp     .end
.set_blocklen_fail:
        mov     ax, 7

.end:
        call    disable

        pop     cx
        pop     bx
        ret

; --------------------------------------------------
; Read single block
; --------------------------------------------------
; Args:
;   AX - block number
;   ES:BX - buffer address
; Return:
;   AX - error code, 0 if success
        global  sdc_read_single_block
sdc_read_single_block:
        push    bx
        push    cx
        push    di

        mov     di, bx

        call    enable

        call    cmd17_read_block
        call    wait_byte       ; Read header
        mov     cx, 1           ; Skip tail
        call    skip
        cmp     al, 0
        jne     .read_block_fail

        call    wait_byte
        cmp     al, 0xfe
        jne     .token_fail

        ; Read block bytes
        mov     cx, 512
.next:
        call    read
        mov     [es:di], al
        inc     di
        loop    .next

        ; Read CRC
        call    read
        call    read

        xor     ax, ax
        jmp     .end

.read_block_fail:
        mov     ax, 1
        jmp     .end
.token_fail:
        mov     ax, 2
        jmp     .end
.end:
        call    disable

        pop     di
        pop     cx
        pop     bx
        ret

; --------------------------------------------------
; Write single block
; --------------------------------------------------
; Args:
;   AX - block number
;   ES:BX - buffer address
; Return:
;   AX - error code, 0 if success
        global  sdc_write_single_block
sdc_write_single_block:
        push    bx
        push    cx

        call    enable

        call    cmd24_write_block
        call    wait_byte       ; Read header
        cmp     al, 0
        jne     .write_block_fail

        ; Idle for 1 byte
        mov     al, 0xff
        call    write

        ; Write token
        mov     al, 0xfe
        call    write

        ; Write block bytes
        mov     cx, 512
.next:
        mov     al, [es:bx]
        call    write
        inc     bx
        loop    .next

        ; Write CRC
        mov     al, 0xff
        call    write
        call    write

        ; Read data response
        call    wait_byte
        and     al, 00011111b
        cmp     al, 00000101b
        jne     .data_not_accepted

        ; Wait for card to finish writing
        call    busy

        xor     ax, ax
        jmp     .end

.write_block_fail:
        mov     ax, 1
        jmp     .end
.data_not_accepted:
        mov     ax, 2
        jmp     .end
.end:
        call    disable

        pop     cx
        pop     bx
        ret


cmd0_go_idle_state:
        push    ax

        mov     al, 0 | SDC_HEADER
        call    write
        mov     al, 0  ; arguments
        call    write
        call    write
        call    write
        call    write
        mov     al, 0x95  ; CRC and stop bit
        call    write

        pop     ax
        ret
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

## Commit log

2023-09-23 Initial schematic
    [main.kicad_pcb, main.kicad_sch]
2023-09-25 First prototype without I/O
    [main.kicad_sch]
2023-09-25 Add interrupt controller & display
    [main.kicad_pcb, main.kicad_sch]
2023-09-25 Initial ROM assembly
2023-09-26 Add parallel port
    [jk_clock.kicad_sch, main.kicad_pcb, main.kicad_sch]
2023-09-27 Add Freerouting PCB
    [1 - F.Cu.gbr, 2 - B.Cu.gbr, Board.gbr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]
2023-09-27 Corrected version of v1 PCB
    [Board.gbr, Bot.gbr, BotMask.gbr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]
2023-09-28 Mark as v02
    [Board.gbr, Bot.gbr, BotMask.gbr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]
2023-09-28 Update PCB image
    [main.kicad_pcb]
2023-09-28 Update PCB
2023-09-29 Add I/O sheet
    [io.kicad_sch, main.kicad_pcb, main.kicad_sch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]
2023-09-29 Tie HOLD low, add GAL simulation for clock, add 8253 clock
    [main.kicad_pcb, main.kicad_sch]
2023-10-01 Add UART
    [io.kicad_sch, main.kicad_sch]
2023-10-02 Add UART & uSD card
    [io.kicad_sch, main.kicad_pcb, main.kicad_sch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]
2023-10-03 Update symbols
    [io.kicad_sch]
2023-10-03 Move chips to center/bottom
    [main.kicad_pcb, main_unrouted.kicad_pcb]
2023-10-04 Update PCB label
    [main.kicad_pcb]
2023-10-04 Realign assembly code
2023-10-06 Add 8259 interrupt controller, update PCB
    [io.kicad_sch, main.kicad_pcb, main.kicad_sch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]
2023-10-08 135x160 board
    [io.kicad_sch, main.kicad_pcb, main.kicad_sch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]
2023-10-09 Add second GAL
    [io.kicad_sch, main.kicad_sch]
2023-10-09 PCB 2.0 RC
    [io.kicad_sch, main.kicad_pcb, main.kicad_sch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]
2023-10-10 Cleaner PCB
    [main.kicad_pcb, main.kicad_sch, main_unrouted.kicad_pcb]
2023-10-10 Even better PCB
    [main.kicad_pcb, main_unrouted.kicad_pcb]
2023-10-10 Update logo
    [main.kicad_pcb]
2023-10-10 Final PCB
    [io.kicad_sch, main.kicad_pcb, main.kicad_sch]
2023-10-10 Add RTC interrupt stub
2023-10-11 New PCB (add MCB line)
    [io.kicad_sch, main.kicad_pcb, main.kicad_sch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]
2023-10-13 Add T6963 deiver, fix PPI address in I/O decoder, fix T6963C symbol
    [io.kicad_sch]
2023-10-13 Basic UART support
2023-10-14 Implement UART receive
2023-11-09 Add comments to UART init code
2023-11-10 Add SD card support, fix LCD init sequence
    [main.asm, sdcard.asm, uart.asm]
2023-11-13 Add memtest & hex printing functions
2023-11-18 Add unimplemented interrupt notifications, add Ukrainian font
2023-11-18 Improve SPI read function
2023-11-18 Improve SPI performance
2023-11-19 Add macro to set carry flag in interrupts
2023-11-20 Fix interrupts clobbering bx register, first ELKS test
    [int10h.asm, int14h.asm]
2023-11-21 Improve SPI read speed
2023-11-25 PS/2 with GAL - finally
    [io.kicad_sch]
2023-11-26 V0.3 WIP
    [io.kicad_sch, main.kicad_pcb, main.kicad_sch]
2023-11-26 WIP: PCB v3.0
    [io.kicad_sch, main.kicad_pcb, main.kicad_sch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]
2023-11-29 WIP: SPI
2023-11-30 Final SPI equations
2023-11-30 Add SPI controller to PCB v0.3
    [io.kicad_sch, main.kicad_pcb, main.kicad_sch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]
2023-12-01 Fix nasty bug with gotoxy not setting ES properly
    [int10h.asm, main.asm, uart.asm]
2023-12-01 Fix int 10h function 0ah
    [int10h.asm]
2023-12-02 Fix BIOS screen scrolling (int 10h, function 06h)
    [int10h.asm, main.asm]
2023-12-02 WIP - PCB v0.4
    [io.kicad_sch, main.kicad_pcb, main.kicad_sch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]
2023-12-04 Switch to yasm
2023-12-04 Switch back to nasm since yasm does not generate proper dep files
